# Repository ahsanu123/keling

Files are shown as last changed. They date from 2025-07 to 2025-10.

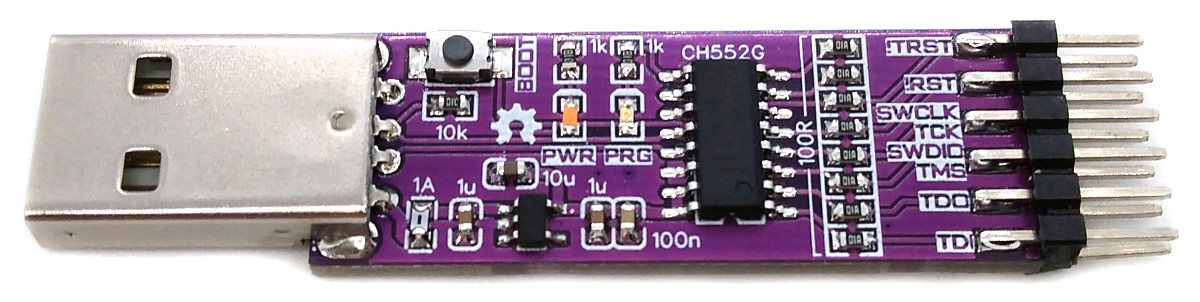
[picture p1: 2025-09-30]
weling/documentation/DAPLink_pic2.jpg

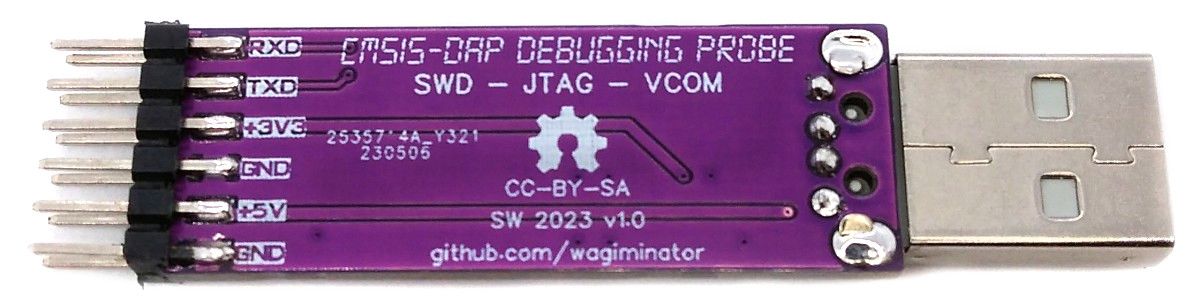
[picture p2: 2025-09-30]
weling/documentation/DAPLink_pic3.jpg

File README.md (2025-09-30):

 <p>
  <a href="">
    
  </a>
  <a href="">
    
  </a>
  <a href="">
    
  </a>
  <a href="https://github.com/ahsanu123/keling/blob/main/LICENSE">
    
  </a>
</p>

<p align="center">
 
</p>
 
<p align="center">
   <b> Keling - DAP Link Collection </b>
</p> 

- pikolink CMSIS DAP with RP2040 and yapicoprobe
- weling CMSIS DAP With CH55x and sdcc

## 🐑 References

- make new project Piko, picoprobe based on https://github.com/ErichStyger/mcuoneclipse/tree/master/KiCAD/Projects/PicoLink
- wagiminator ch552 daplink https://github.com/wagiminator/CH552-DAPLink
- yapicoprobe https://github.com/rgrr/yapicoprobe/blob/master/doc/hardware.adoc
- mcu on eclipse picolink https://mcuoneclipse.com/2023/04/08/open-source-picolink-raspberry-pi-rp2040-cmsis-dap-debug-probe/

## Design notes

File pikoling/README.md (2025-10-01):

<h1>🐤 piko </h1>
<p>
  <a href="">
    
  </a>
  <a href="">
    
  </a>
  <a href="">
    
  </a>
  <a href="https://github.com/ahsanu123/piko/blob/main/LICENSE">
    
  </a>
</p>

<p align="center">    
  
</p>

<p align="center">CMSIS DAP Probe</p>

### 🧺 Schematic

schematic

## 🌳 Log

- 12 September 2025, ⏰ 19:17. success to flash [yapicoprobe-0124-pico-9aff542.uf2](https://github.com/rgrr/yapicoprobe/releases/tag/v1.24) firmware
  - to upload firmware connect usb c to pc while press reset button, there will new usb mass device detected, copy `uf2` file into that rp2040 usb mass device, and chip will be flashed.
- 12 September 2025, ⏰ 19:49, 🐛 BUG 1, remove 100 ohm resistor between SWDIO, SWCLK and pinhead connector, adding 100 ohm resistor make probing not work.

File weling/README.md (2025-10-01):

<h1> 🐍 Weling </h1>
<p>
  <a href="">
    
  </a>
  <a href="">
    
  </a>
  <a href="">
    
  </a>
  <a href="https://github.com/ahsanu123/piko/blob/main/LICENSE">
    
  </a>
</p>

<p align="center">     
  
</p>

<p align="center">CMSIS DAP Probe With CH552G</p>

### 🧺 Schematic

schematic

## 🌳 Log

- 1 Oktober 2025, ⏰ 19:37. Finish Make Schematic and Routing.

## 🩹 Rerence

- CH55x Library ->  https://github.com/devbisme/KiCad-Schematic-Symbol-Libraries/blob/master/wch.lib

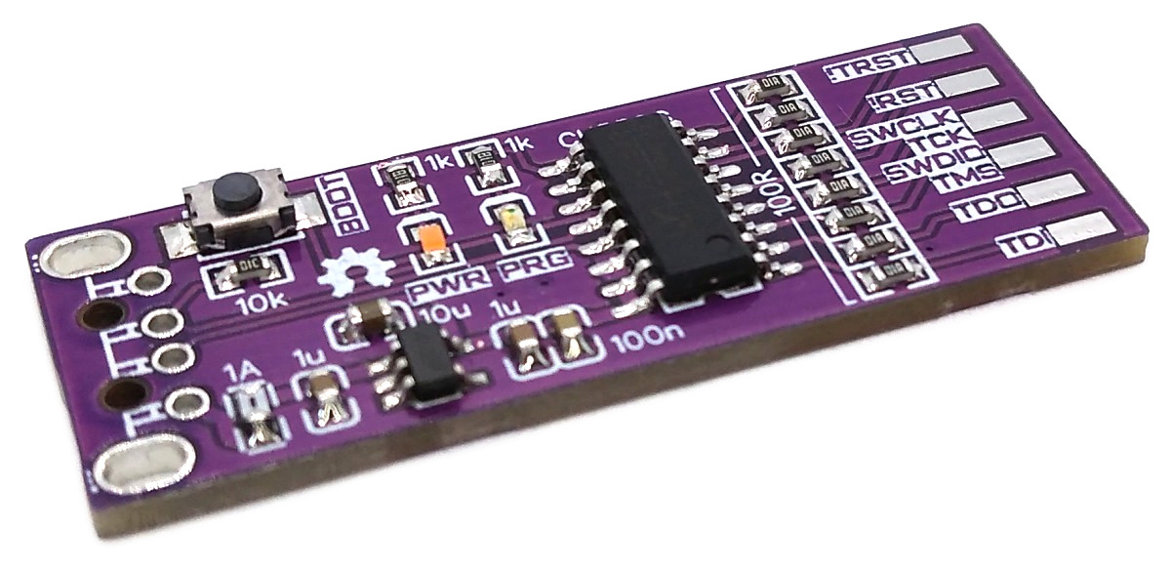
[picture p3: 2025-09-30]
weling/documentation/DAPLink_pic4.jpg

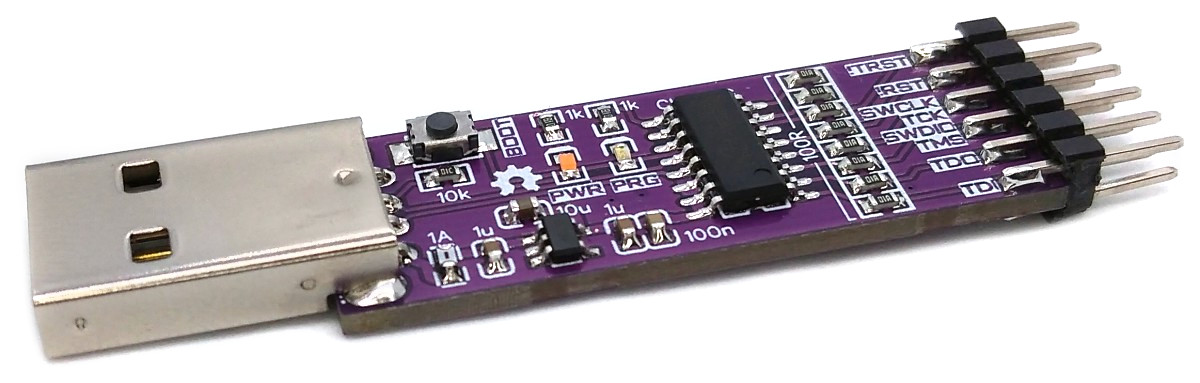
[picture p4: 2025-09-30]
weling/documentation/DAPLink_pic1.jpg

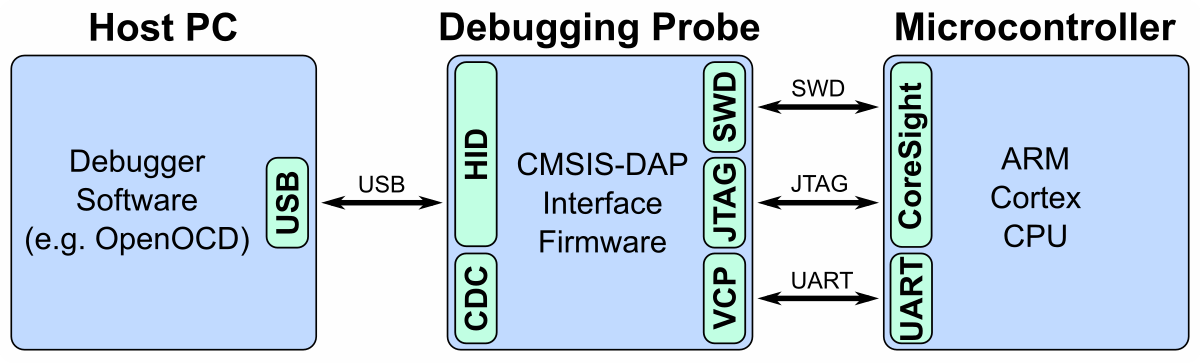
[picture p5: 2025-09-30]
weling/documentation/DAPLink_CMSIS-DAP.png

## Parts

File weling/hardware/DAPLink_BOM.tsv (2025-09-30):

ID | Name | Designator | Footprint | Quantity | Manufacturer Part | Manufacturer | Supplier | Supplier Part
1 | 100n | C1 | C_0603 | 1 | CC0603KRX7R9BB104 | YAGEO | LCSC | C14663
2 | 10u | C2 | C_0603 | 1 | CL10A106KP8NNNC | SAMSUNG | LCSC | C19702
3 | 1u | C3,C4 | C_0603 | 2 | CL10A105KB8NNNC | SAMSUNG(三星) | LCSC | C15849
4 | 1A | F1 | F0603 | 1 | BSMD0603L-100 | BHFUSE(佰宏) | LCSC | C2757929
5 | HDR | H1 | HDR-12-SIDE | 1 |  |  | LCSC | C124388
6 | PRG | LED1 | LED0603 | 1 | KT-0603R | KENTO | LCSC | C2286
7 | PWR | LED2 | LED0603 | 1 | 19-217/GHC-YR1S2/3T | EVERLIGHT | LCSC | C72043
8 | 10k | R1 | 0603 | 1 | 0603WAF1002T5E | UniOhm | LCSC | C25804
9 | 1k | R2,R3 | 0603 | 2 | 0603WAF1001T5E | UniOhm | LCSC | C21190
10 | 100R | R4,R5,R6,R7,R8,R9,R10,R11 | 0603 | 8 | 0603WAF1000T5E | UNI-ROYAL(厚声) | LCSC | C22775
11 | BOOT | SW1 | SW-SMD_L4.0-W2.9-LS5.0 | 1 | TS-1185-C-A-B-B | XKB Enterprise | LCSC | C465999
12 | CH552G | U1 | SOP-16_150MIL | 1 | CH552G | WCH(南京沁恒) | LCSC | C111292
13 | AP2112K-3.3TRG1 | U2 | SOT-25-5 | 1 | AP2112K-3.3TRG1 | DIODES | LCSC | C51118
14 | USB-Plug | USB1 | USB-M-48 | 1 | USB-05 | SOFNG | LCSC | C112454

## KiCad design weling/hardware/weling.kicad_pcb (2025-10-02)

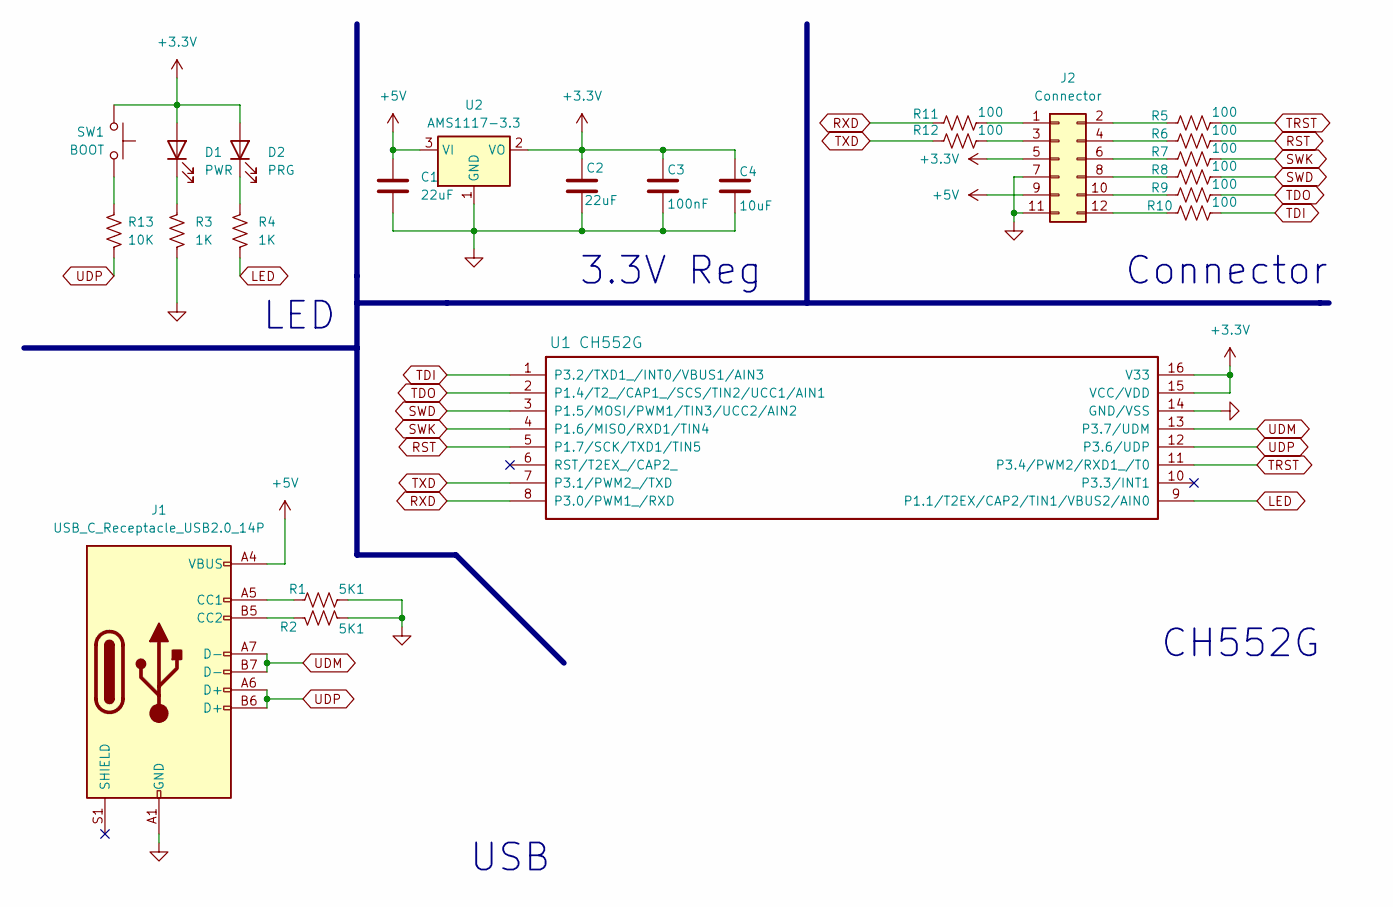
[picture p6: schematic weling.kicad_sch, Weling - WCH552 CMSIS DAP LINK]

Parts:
C1, C2: 22uF; C_0805_2012Metric_Pad1.18x1.45mm_HandSolder
C3: 100nF; C_0805_2012Metric_Pad1.18x1.45mm_HandSolder
C4: 10uF; C_0805_2012Metric_Pad1.18x1.45mm_HandSolder
D1: PWR; LED_1206_3216Metric_Pad1.42x1.75mm_HandSolder
D2: PRG; LED_1206_3216Metric_Pad1.42x1.75mm_HandSolder
J1: USB_C_Receptacle_USB2.0_14P; USB_C_Receptacle_GCT_USB4110
J2: Connector; IDC-Header_2x06_P2.54mm_Vertical
R1, R2: 5K1; R_0805_2012Metric_Pad1.20x1.40mm_HandSolder
R3, R4: 1K; R_0805_2012Metric_Pad1.20x1.40mm_HandSolder
R5, R6, R7, R8, R9, R10, R11, R12: 100; R_0805_2012Metric_Pad1.20x1.40mm_HandSolder
R13: 10K; R_0805_2012Metric_Pad1.20x1.40mm_HandSolder
SW1: BOOT; SW_Push_1P1T_NO_6x6mm_H9.5mm
U1: CH552G; STC_SOP-16_3.9x9.9mm_P1.27mm
U2: AMS1117-3.3; SOT-223-3_TabPin2

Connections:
+3.3V: C2.1, C3.1, C4.1, D1.2 (A), D2.2 (A), J2.5, SW1.2, U1.15 (VCC/VDD), U1.16 (V33), U2.2 (VO)
+5V: C1.1, J1.A4 (VBUS), J1.A9 (VBUS), J1.B4 (VBUS), J1.B9 (VBUS), J2.9, U2.3 (VI)
GND: C1.2, C2.2, C3.2, C4.2, J1.A1 (GND), J1.A12 (GND), J1.B1 (GND), J1.B12 (GND), J2.7, J2.11, R1.2, R2.2, R3.1, U1.14 (GND/VSS), U2.1 (GND)
LED: R4.1, U1.9 (P1.1/T2EX/CAP2/TIN1/VBUS2/AIN0)
unnamed: D1.1 (K), R3.2
unnamed: D2.1 (K), R4.2
unnamed: J1.A5 (CC1), R1.1
unnamed: J1.B5 (CC2), R2.1
unnamed: J2.1, R11.2
unnamed: J2.2, R5.1
unnamed: J2.3, R12.2
unnamed: J2.4, R6.1
unnamed: J2.6, R7.1
unnamed: J2.8, R8.1
unnamed: J2.10, R9.1
unnamed: J2.12, R10.1
unnamed: R13.2, SW1.1
RST: R6.2, U1.5 (P1.7/SCK/TXD1/TIN5)
RXD: R11.1, U1.8 (P3.0/PWM1_/RXD)
SWD: R8.2, U1.3 (P1.5/MOSI/PWM1/TIN3/UCC2/AIN2)
SWK: R7.2, U1.4 (P1.6/MISO/RXD1/TIN4)
TDI: R10.2, U1.1 (P3.2/TXD1_/INT0/VBUS1/AIN3)
TDO: R9.2, U1.2 (P1.4/T2_/CAP1_/SCS/TIN2/UCC1/AIN1)
TRST: R5.2, U1.11 (P3.4/PWM2/RXD1_/T0)
TXD: R12.1, U1.7 (P3.1/PWM2_/TXD)
UDM: J1.A7 (D-), J1.B7 (D-), U1.13 (P3.7/UDM)
UDP: J1.A6 (D+), J1.B6 (D+), R13.1, U1.12 (P3.6/UDP)

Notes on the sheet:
3.3V Reg
LED
USB
Connector
CH552G

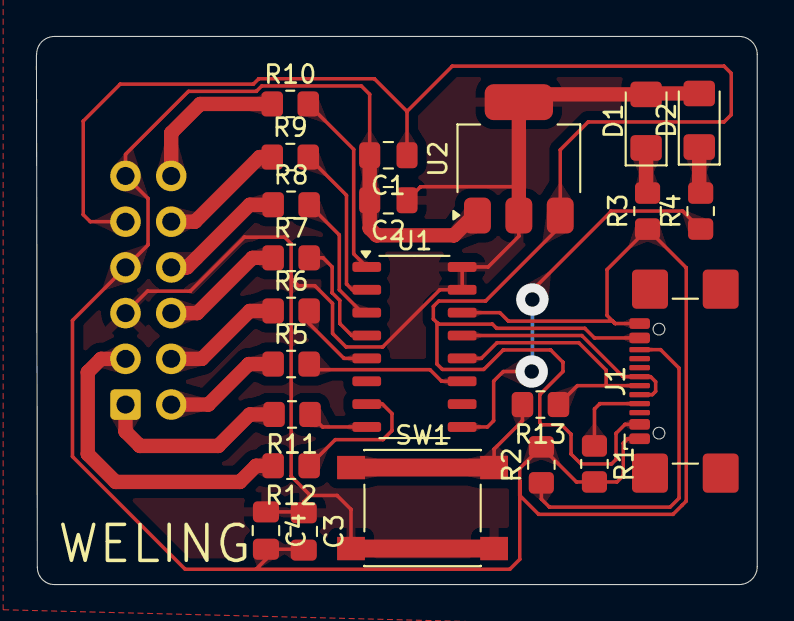
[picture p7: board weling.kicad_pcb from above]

Board: 2 copper layers, 40.0 x 30.5 mm, 24 parts (1 on the bottom side), 27 nets.

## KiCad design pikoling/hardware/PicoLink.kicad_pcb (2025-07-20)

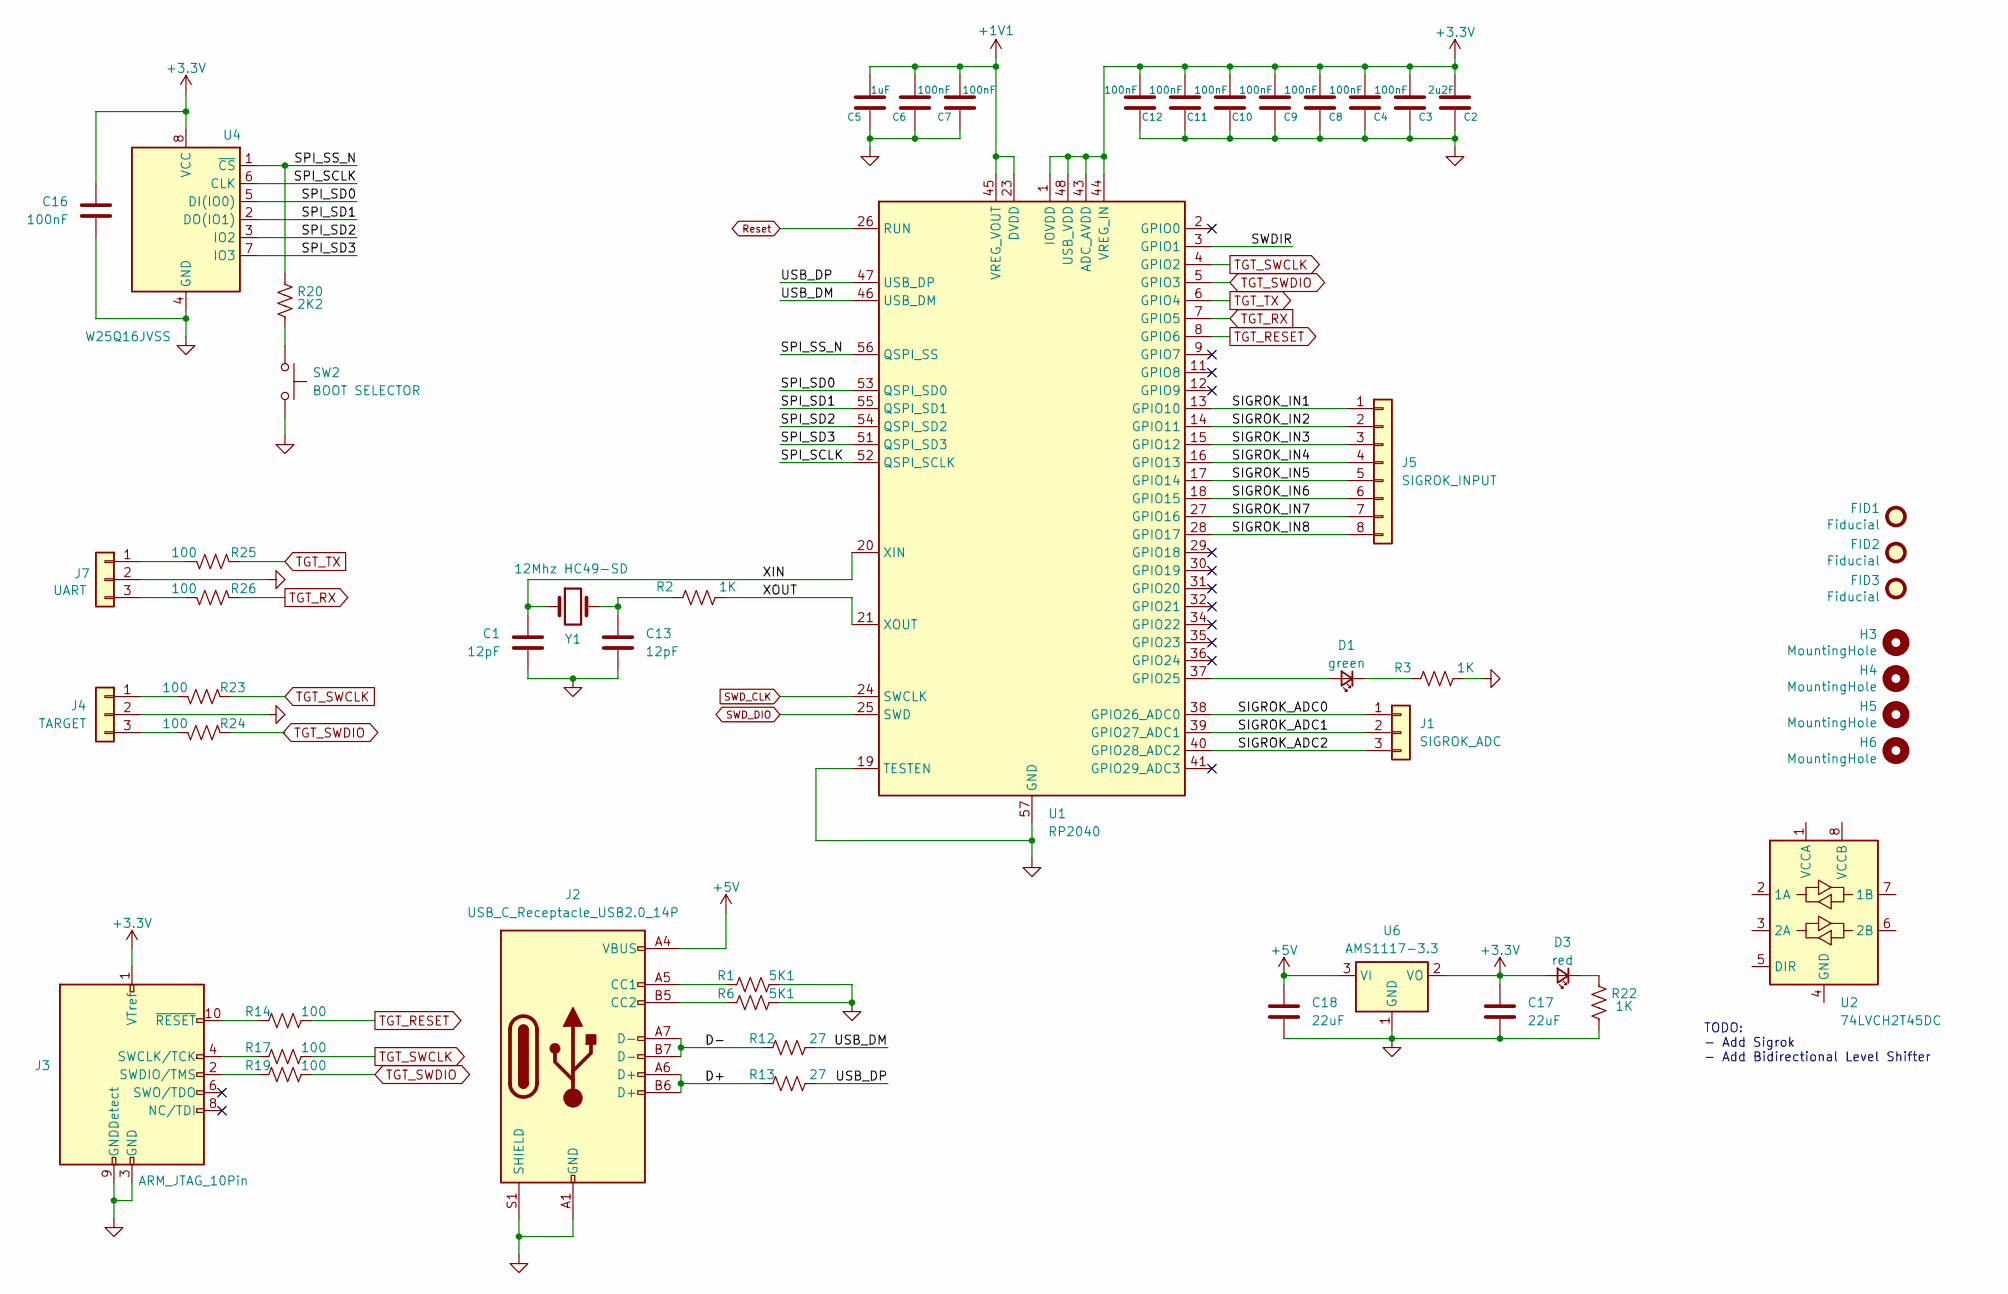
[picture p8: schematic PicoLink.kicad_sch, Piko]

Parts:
C1, C13: 12pF; C_0603_1608Metric_Pad1.08x0.95mm_HandSolder
C2: 2u2F; C_0603_1608Metric_Pad1.08x0.95mm_HandSolder
C3, C4, C6, C7, C8, C9, C10, C11, C12, C16: 100nF; C_0603_1608Metric_Pad1.08x0.95mm_HandSolder
C5: 1uF; C_0603_1608Metric_Pad1.08x0.95mm_HandSolder
C17, C18: 22uF; C_0603_1608Metric_Pad1.08x0.95mm_HandSolder
D1: green; LED_0805_2012Metric_Pad1.15x1.40mm_HandSolder; mouser# 78-VLMTG1300-GS08
D3: red; LED_0805_2012Metric_Pad1.15x1.40mm_HandSolder; mouser# 78-VLMS1300-GS08
FID1, FID2, FID3: Fiducial; Fiducial_1mm_Mask2mm
H3, H4, H5, H6: MountingHole; MountingHole_2.7mm_M2.5
J1: SIGROK_ADC; PinHeader_1x03_P2.54mm_Vertical
J2: USB_C_Receptacle_USB2.0_14P; USB_C_Receptacle_GCT_USB4110
J3: ARM_JTAG_10Pin; IDC-Header_2x05_P2.54mm_Vertical
J4: TARGET; PinHeader_1x03_P2.54mm_Vertical
J5: SIGROK_INPUT; PinHeader_1x07_P2.54mm_Vertical
J7: UART; PinHeader_1x03_P2.54mm_Vertical
R1, R6: 5K1; R_0805_2012Metric_Pad1.20x1.40mm_HandSolder
R2, R3, R22: 1K; R_0805_2012Metric_Pad1.20x1.40mm_HandSolder
R12, R13: 27; R_0805_2012Metric_Pad1.20x1.40mm_HandSolder
R14, R17, R19, R23, R24, R25, R26: 100; R_0805_2012Metric_Pad1.20x1.40mm_HandSolder
R20: 2K2; R_0805_2012Metric_Pad1.20x1.40mm_HandSolder
SW2: BOOT SELECTOR; SW_Push_1P1T_NO_6x6mm_H9.5mm
U1: RP2040; QFN-56-1EP_7x7mm_P0.4mm_EP3.2x3.2mm
U2: 74LVCH2T45DC; VSSOP-8_2.3x2mm_P0.5mm
U4: W25Q16JVSS; SOIC-8_5.23x5.23mm_P1.27mm
U6: AMS1117-3.3; SOT-223-3_TabPin2
Y1: 12Mhz HC49-SD; Crystal_SMD_HC49-SD

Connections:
+1V1: C5.1, C6.1, C7.1, U1.23 (DVDD), U1.45 (VREG_VOUT), U1.50 (DVDD)
+3.3V: C2.1, C3.1, C4.1, C8.1, C9.1, C10.1, C11.1, C12.1, C16.1, C17.1, D3.2 (A), J3.1 (VTref), U1.1 (IOVDD), U1.10 (IOVDD), U1.22 (IOVDD), U1.33 (IOVDD), U1.42 (IOVDD), U1.43 (ADC_AVDD), U1.44 (VREG_IN), U1.48 (USB_VDD), U1.49 (IOVDD), U4.8 (VCC), U6.2 (VO)
+5V: C18.1, J2.A4 (VBUS), J2.A9 (VBUS), J2.B4 (VBUS), J2.B9 (VBUS), U6.3 (VI)
/D+: J2.A6 (D+), J2.B6 (D+), R13.1
/D-: J2.A7 (D-), J2.B7 (D-), R12.1
/SIGROK_ADC0: J1.1, U1.38 (GPIO26_ADC0)
/SIGROK_ADC1: J1.2, U1.39 (GPIO27_ADC1)
/SIGROK_ADC2: J1.3, U1.40 (GPIO28_ADC2)
/SIGROK_IN1: J5.1, U1.13 (GPIO10)
/SIGROK_IN2: J5.2, U1.14 (GPIO11)
/SIGROK_IN3: J5.3, U1.15 (GPIO12)
/SIGROK_IN4: J5.4, U1.16 (GPIO13)
/SIGROK_IN5: J5.5, U1.17 (GPIO14)
/SIGROK_IN6: J5.6, U1.18 (GPIO15)
/SIGROK_IN7: J5.7, U1.27 (GPIO16)
/SIGROK_IN8: J5.8, U1.28 (GPIO17)
/SPI_SCLK: U1.52 (QSPI_SCLK), U4.6 (CLK)
/SPI_SD0: U1.53 (QSPI_SD0), U4.5 (DI(IO0))
/SPI_SD1: U1.55 (QSPI_SD1), U4.2 (DO(IO1))
/SPI_SD2: U1.54 (QSPI_SD2), U4.3 (IO2)
/SPI_SD3: U1.51 (QSPI_SD3), U4.7 (IO3)
/SPI_SS_N: R20.1, U1.56 (QSPI_SS), U4.1 (~CS)
/SWDIR: U1.3 (GPIO1)
/USB_DM: R12.2, U1.46 (USB_DM)
/USB_DP: R13.2, U1.47 (USB_DP)
/XIN: C1.1, U1.20 (XIN), Y1.1
/XOUT: R2.2, U1.21 (XOUT)
GND: C1.2, C2.2, C3.2, C4.2, C5.2, C6.2, C7.2, C8.2, C9.2, C10.2, C11.2, C12.2, C13.2, C16.2, C17.2, C18.2, J2.A1 (GND), J2.A12 (GND), J2.B1 (GND), J2.B12 (GND), J2.S1 (SHIELD), J3.3 (GND), J3.5 (GND), J3.9 (GNDDetect), J4.2, J7.2, R1.2, R3.2, R6.2, R22.2, SW2.2, U1.19 (TESTEN), U1.57 (GND), U4.4 (GND), U6.1 (GND)
unnamed: C13.1, R2.1, Y1.2
unnamed: D1.2 (A), U1.37 (GPIO25)
unnamed: D1.1 (K), R3.1
unnamed: D3.1 (K), R22.1
unnamed: J2.A5 (CC1), R1.1
unnamed: J2.B5 (CC2), R6.1
unnamed: J3.4 (SWCLK/TCK), R17.1
unnamed: J3.2 (SWDIO/TMS), R19.1
unnamed: J3.10 (~RESET), R14.1
unnamed: J4.1, R23.2
unnamed: J4.3, R24.2
unnamed: J7.1, R25.2
unnamed: J7.3, R26.2
unnamed: R20.2, SW2.1
Reset: U1.26 (RUN)
SWD_CLK: U1.24 (SWCLK)
SWD_DIO: U1.25 (SWD)
TGT_RESET: R14.2, U1.8 (GPIO6)
TGT_RX: R26.1, U1.7 (GPIO5)
TGT_SWCLK: R17.2, R23.1, U1.4 (GPIO2)
TGT_SWDIO: R19.2, R24.1, U1.5 (GPIO3)
TGT_TX: R25.1, U1.6 (GPIO4)

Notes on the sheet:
TODO: - Add Sigrok - Add Bidirectional Level Shifter

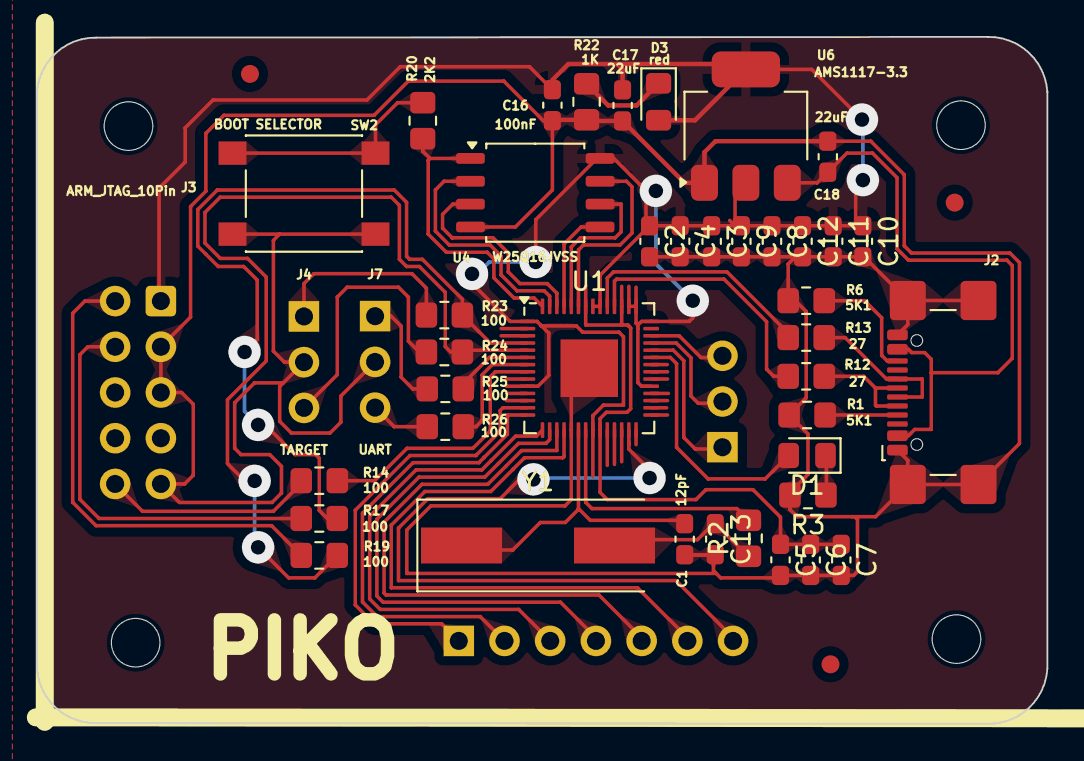
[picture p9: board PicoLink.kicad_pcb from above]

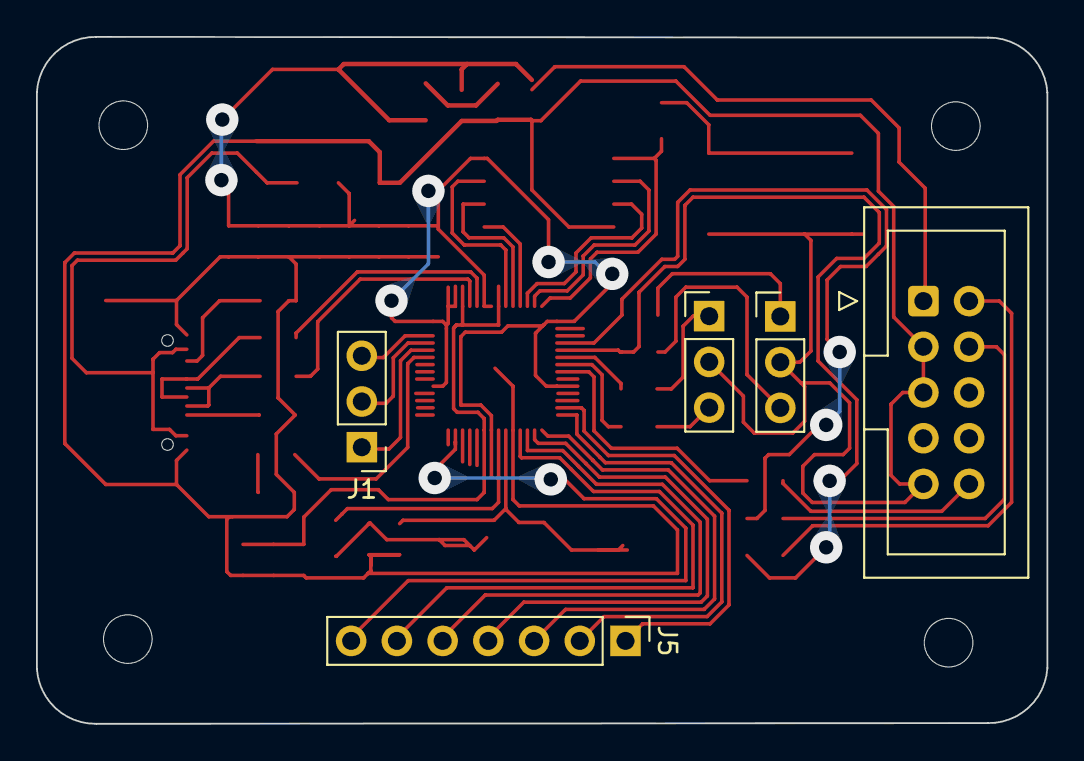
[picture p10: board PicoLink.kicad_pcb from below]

Board: 2 copper layers, 56.1 x 38.2 mm, 51 parts (5 on the bottom side), 45 nets.

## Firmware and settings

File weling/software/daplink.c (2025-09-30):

// ===================================================================================
// Project:   DAPLink - CMSIS-DAP compliant debugging probe with VCP based on CH552
// Version:   v1.0
// Year:      2023
// Author:    Stefan Wagner
// Github:    https://github.com/wagiminator
// EasyEDA:   https://easyeda.com/wagiminator
// License:   http://creativecommons.org/licenses/by-sa/3.0/
// ===================================================================================
//
// Description:
// ------------
// The CH552-based DAPLink is a CMSIS-DAP compliant debugging probe with SWD and JTAG
// protocol support. It can be used to program Microchip SAM and other ARM-based
// microcontrollers. The additional Virtual COM Port (VCP) provides an additional
// debugging feature. The SWD-part of the firmware is based on Ralph Doncaster's 
// DAPLink-implementation for CH55x microcontrollers and Deqing Sun's CH55xduino port.
//
// References:
// -----------
// - Blinkinlabs: https://github.com/Blinkinlabs/ch554_sdcc
// - Deqing Sun: https://github.com/DeqingSun/ch55xduino
// - Ralph Doncaster: https://github.com/nerdralph/ch554_sdcc
// - WCH Nanjing Qinheng Microelectronics: http://wch.cn
// - ARMmbed DAPLink: https://github.com/ARMmbed/DAPLink
// - picoDAP: https://github.com/wagiminator/CH552-picoDAP
//
// Compilation Instructions:
// -------------------------
// - Chip:  CH552
// - Clock: 16 MHz internal
// - Adjust the firmware parameters in src/config.h if necessary.
// - Make sure SDCC toolchain and Python3 with PyUSB is installed.
// - Press BOOT button on the board and keep it pressed while connecting it via USB
//   with your PC.
// - Run 'make flash' immediatly afterwards.
//
// Operating Instructions:
// -----------------------
// Connect the DAPLink to the target board via the pin header. You can supply power
// via the 3V3 pin or the 5V pin (max 400 mA). Plug the DAPLink into a USB port on 
// your PC. Since it is recognized as a Human Interface Device (HID), no driver 
// installation is required. However, Windows users may need to install a CDC driver
// for the Virtual COM Port (VCP). The DAPLink should work with any debugging software
// that supports CMSIS-DAP (e.g. OpenOCD or PyOCD). The virtual COM port (8N1 only)
// can be used with any serial monitor.


// ===================================================================================
// Libraries, Definitions and Macros
// ===================================================================================

// Libraries
#include "src/system.h"                     // system functions
#include "src/delay.h"                      // delay functions
#include "src/dap.h"                        // CMSIS-DAP functions
#include "src/usb_cdc.h"                    // USB CDC functions
#include "src/uart.h"                       // UART functions

// Prototypes for used interrupts
void USB_interrupt(void);
void USB_ISR(void) __interrupt(INT_NO_USB) {
  USB_interrupt();
}

void UART_interrupt(void);
void UART_ISR(void) __interrupt(INT_NO_UART0) {
  UART_interrupt();
}

// Number of received bytes in endpoint
extern volatile __xdata uint8_t HID_byteCount;

// ===================================================================================
// Main Function
// ===================================================================================
void main(void) {
  // Setup
  CLK_config();                             // configure system clock
  DLY_ms(10);                               // wait for clock to settle
  UART_init();                              // init UART
  DAP_init();                               // init CMSIS-DAP
  CDC_init();                               // init virtual COM

  // Loop
  while(1) {
    // Handle DAP
    if(HID_byteCount && !UEP1_T_LEN) {      // DAP packet received and out buffer empty?                      
      DAP_Thread();                         // handle DAP packet
      HID_byteCount = 0;                    // clear byte counter
      UEP1_T_LEN = 64;                      // Windows hangs if smaller
      UEP1_CTRL = UEP1_CTRL & ~(MASK_UEP_R_RES | MASK_UEP_T_RES); // send/receive package
    }

    // Handle virtual COM
    if(CDC_available() && UART_ready()) UART_write(CDC_read());
    if(UART_available() && CDC_getDTR()) {
      while(UART_available()) CDC_write(UART_read());
      CDC_flush();
    }
  }
}

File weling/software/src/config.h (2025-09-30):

// ===================================================================================
// User Configurations for CH552 DAPLink
// ===================================================================================

#pragma once

// Pin definitions
#define PIN_LED             P11       // pin connected to LED, active low
#define PIN_SWD             P15       // pin connected to SWDIO/TMS via 100R resistor
#define PIN_SWK             P16       // pin connected to SWCLK/TCK via 100R resistor
#define PIN_RST             P17       // pin connected to nRESET
#define PIN_TDO             P14       // pin connected to TDO via 100R resistor
#define PIN_TDI             P32       // pin connected to TDI via 100R resistor
#define PIN_TRST            P34       // pin connected to nTRST
#define PIN_RXD             P30       // pin connected to RXD via 470R resistor
#define PIN_TXD             P31       // pin connected to TXT via 470R resistor

// USB device descriptor
#define USB_VENDOR_ID       0x1A86    // VID
#define USB_PRODUCT_ID      0x8011    // PID
#define USB_DEVICE_VERSION  0x0100    // v1.0 (BCD-format)

// USB configuration descriptor
#define USB_MAX_POWER_mA    500       // max power in mA 

// USB descriptor strings
#define MANUFACTURER_STR    'w','a','g','i','m','i','n','a','t','o','r'
#define PRODUCT_STR         'D','A','P','L','i','n','k',' ', 'C','M','S','I','S','-','D','A','P'
#define SERIAL_STR          'C','H','5','5','2'
#define INTERFACE_STR_1     'C','M','S','I','S','-','D','A','P',' ','C','D','C'
#define INTERFACE_STR_2     'C','M','S','I','S','-','D','A','P',' ','Q','Y','F'

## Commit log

2025-07-20 [07-20-0908] update gerber and schematic
    [PicoLink-B_Adhesive.gbr, PicoLink-B_Courtyard.gbr, PicoLink-B_Cu.gbr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]
2025-09-30 fork: copying ch552 dap link from wagiminator to weling
    [DAPLink_BOM.tsv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]
2025-10-01 feat: complete schematic and basic routing, need to recheck
    n
    Rename README.md to README_Original.md
    p
    Update README.md
    [weling.kicad_pcb, weling.kicad_sch]
2025-10-02 feat: add decoupling capacitor
    [weling.kicad_pcb, weling.kicad_sch]
